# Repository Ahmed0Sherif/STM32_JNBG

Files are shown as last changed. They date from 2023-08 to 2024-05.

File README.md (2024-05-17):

# Intro
- This repository includes the schematics and PCB design of a double-layer STM32 development Board.
- The code name "JNBG" is in the honour of my group who helped and encouraged me in this project.
- The design is done on KiCAD 6.0
# Components List:
|Component|Description|Quantity| Was Used|
|----|-----|---|---|
|STM32f030f4p6|ARM® Cortex®-M0 48MHz FLASH 2.4V ~ 3.6V 32-Bit TSSOP-20 ST Microelectronics|1|Yes|
|AMS1117- 3V3| 3V3 LDO Linear Voltage Regulator  SOT-223-3|1|Yes|
|CH340C|IC Transceiver USB 2.0 2Mbps SOP-16|1|Yes|
|USBLC6-2SC6|ESD Protection TVS Unidirectional Dual Array SOT23-6|1|Yes|
|SMAJ5.0A|Unidirectional TVS 5.0V DO-214AC|1|Not Available|
|Crystal Oscillator|Crystal Oscillator 32MHz 3225|1|Yes|
|LEDs|Green and Red LEDs 0805|1* Green, 1*Red|Yes|
|Ferrite Bead|100Ω @ 100MHz 2.5A 1 100mΩ 0805|1|Yes|
|22uF Capacitor|SMD 22uF 0805|2|Replaced with 1205 Counterpart|
|4.7uF Capacitor|SMD 4.7uF 0603|2|Yes|
|1uF Capacitor|SMD 1uF 0603|2|Yes|
|100n Capacitor|SMD 100nF 0603|1|Yes|
|47nF Capacitor|SMD 47nF 0805|1|Yes|
|10nF Capacitor|SMD 10nF 0603|1|Yes|
|10pF Capacitor|SMD 10pF 0603|2|Yes|
|10k ohm Resistor|SMD 10k 0603|3|Yes|
|1k ohm Resistor|SMD 1k 0603|1|Yes|
|1k5 ohm Resistor|SMD 1k5 0603|3|Yes|
|Tactile Push Button|Micro Push button Switch 2P 3x4x2mm|1|Yes|
|PCB TH SPDT Toggle Switch| Through Hole SPDT Swithc pitch = 2.54mm |1|Yes|
|USB Port|SMD USB-B-Micro |1|Yes|
|Female Headers|TH Female Headers Vertical pitch = 2.54mm|13|Yes|
# Schematics:
## A-Power Module:
<p align="center">

 </p>
<br> - In this circuit, the AMS1117 is used to regulate 5V from USB to 3.3V, with a unidirectional TVS to protect against surges.

## B-USB Interface:
<p align="center">

 </p>
<br> - The board is provided with a USB-B Micro port, providing power and communication to the controller. 
<br> - The differential pair is connected to au nidirectional Dual TVS for ESD protection. Finally, the differentials are connected to a USB-to-TTL interface: CH340C. This variant was chosen because it can operate without an external crystal.
<br> - It is worth mentioning that until this time, this module has not been tested yet.

## C-Main Controller:
<p align="center">

 </p>
### a- Crystal Oscillator
- For calculting the value of capacitors, the following equation is used:
<br>   Capacitor Value =  ( Load Capaitance of Crystal [10pf] + Stray Capacitance of PCB [maximum estimate = 10pF] ) / 2
- Source: Phill's Lab Course on KiCAD 6.0
### b- Power:
- According to the datasheet of STM32f03x, it is recommeded to connect VDD pin to the shown capacitances.
- For more stable ADC performance, a ferrite bead is added to the VDDA connections.
### c- Interfacing:
- GPIO pins are connected to headers for easier interface, while taking speical signals into considerations (i.e. I2C pair)
- A SPDT switch is added to control the BOOT0 pin, and a RST button is added.
- For experimental purposes, extra pair of headers are added to power the STM32 directly, bypassing the regulator.

# PCB View:
<p align="center">
2D View
 </p>
<p align="center">
3D View - Front
 </p>
<p align="center">
3D View - Back
 </p>
 
# Final Result:
<p align="center">
Homemade PCB
 </p>

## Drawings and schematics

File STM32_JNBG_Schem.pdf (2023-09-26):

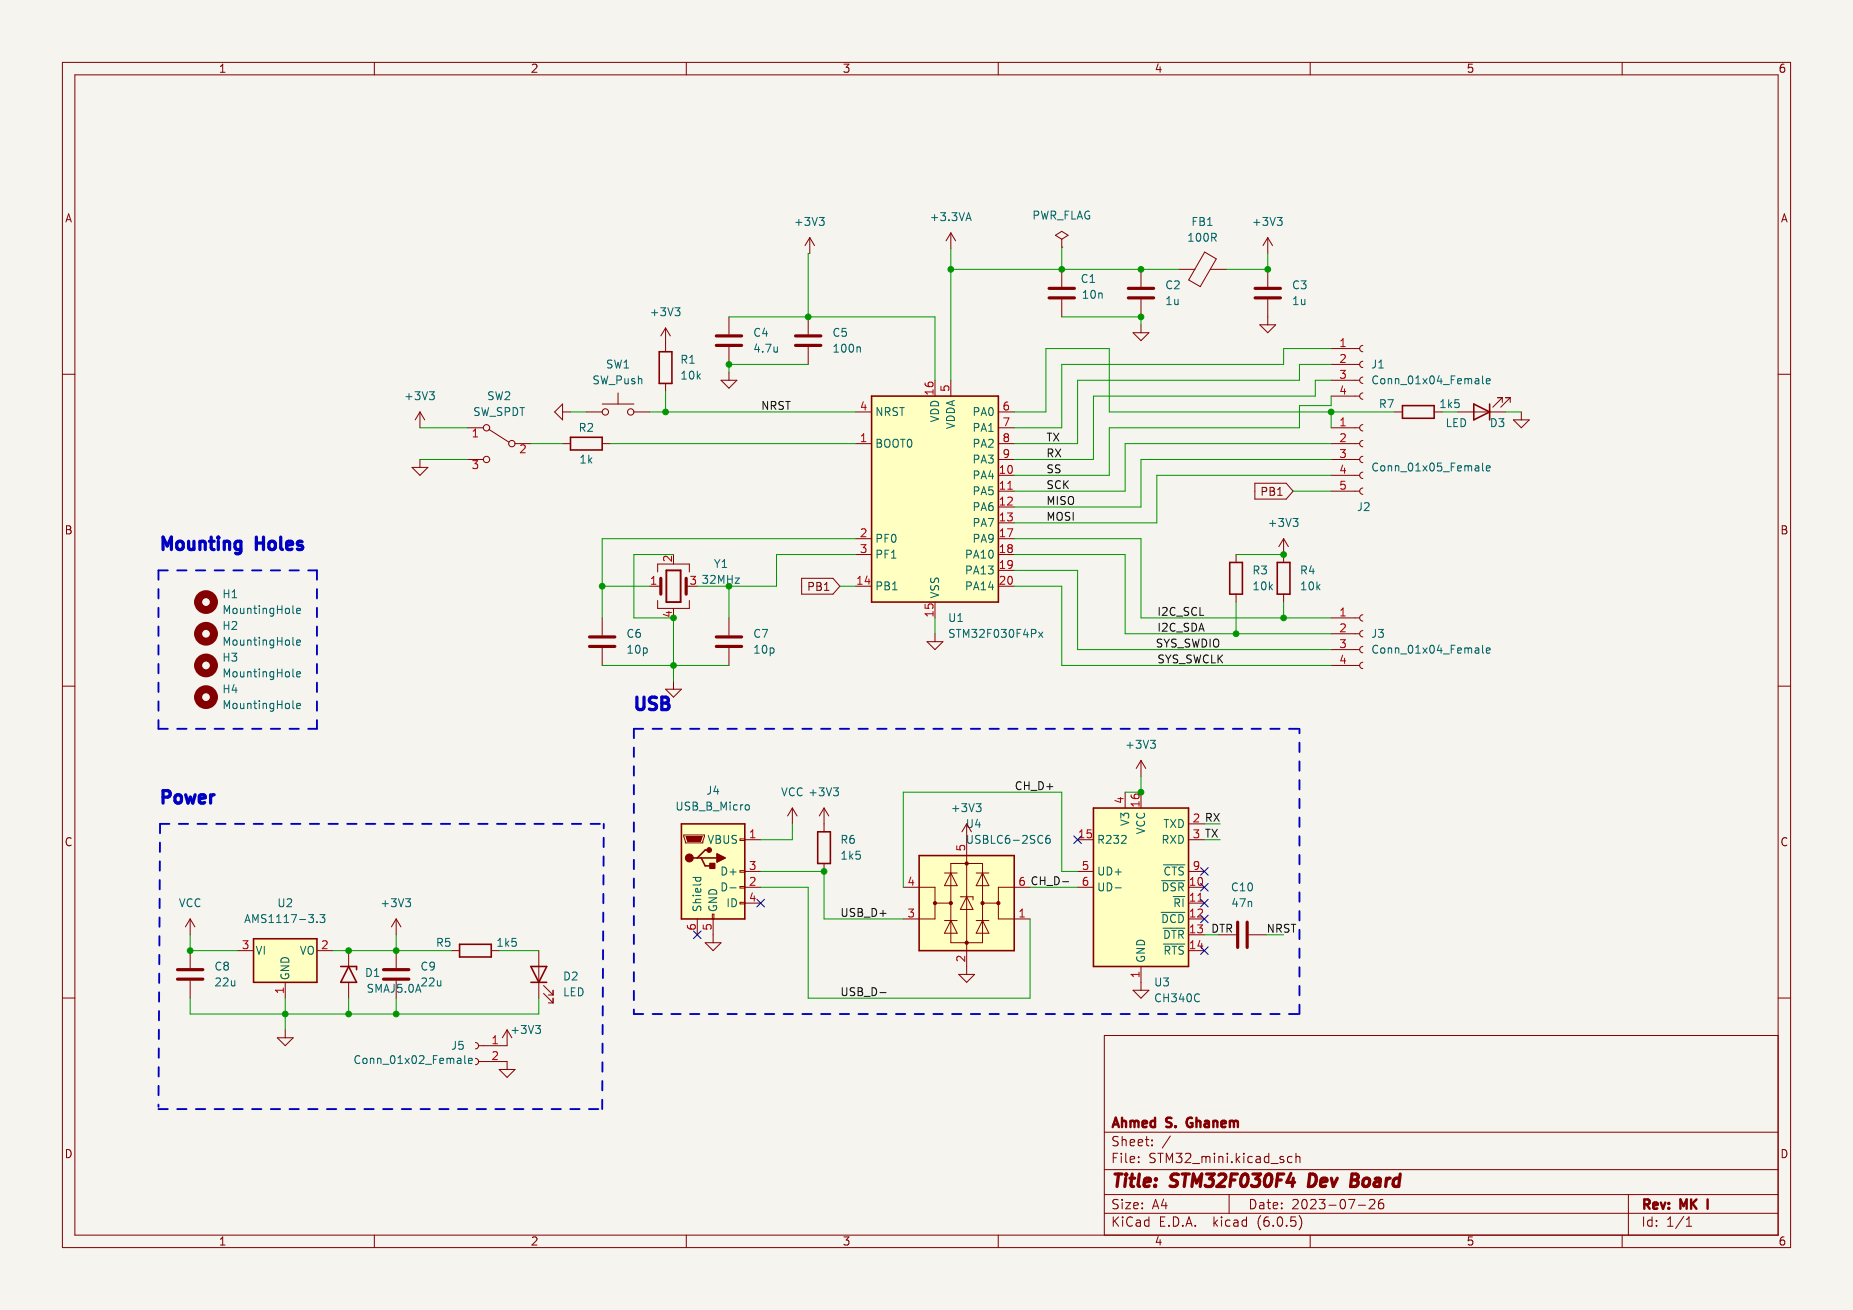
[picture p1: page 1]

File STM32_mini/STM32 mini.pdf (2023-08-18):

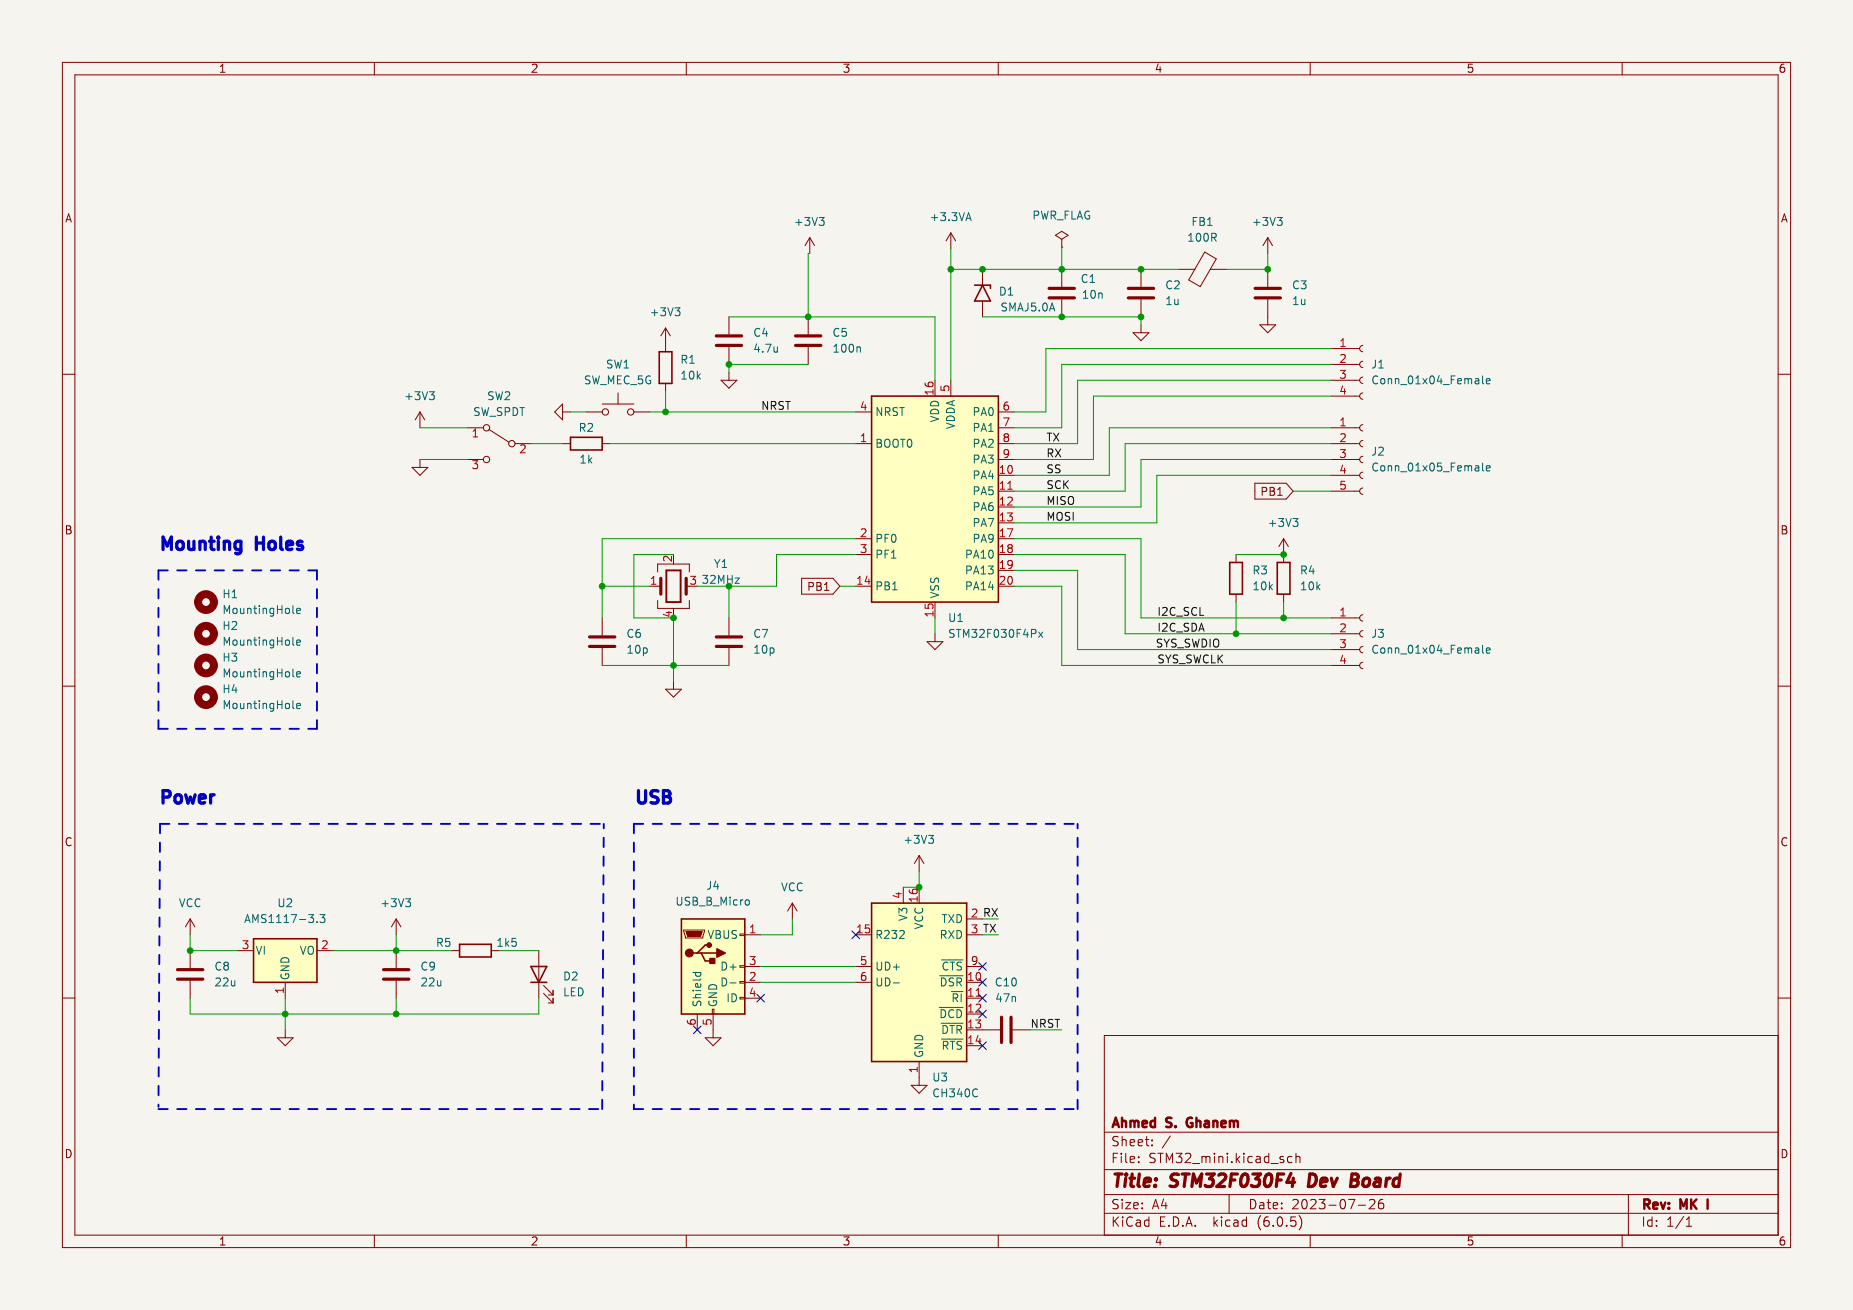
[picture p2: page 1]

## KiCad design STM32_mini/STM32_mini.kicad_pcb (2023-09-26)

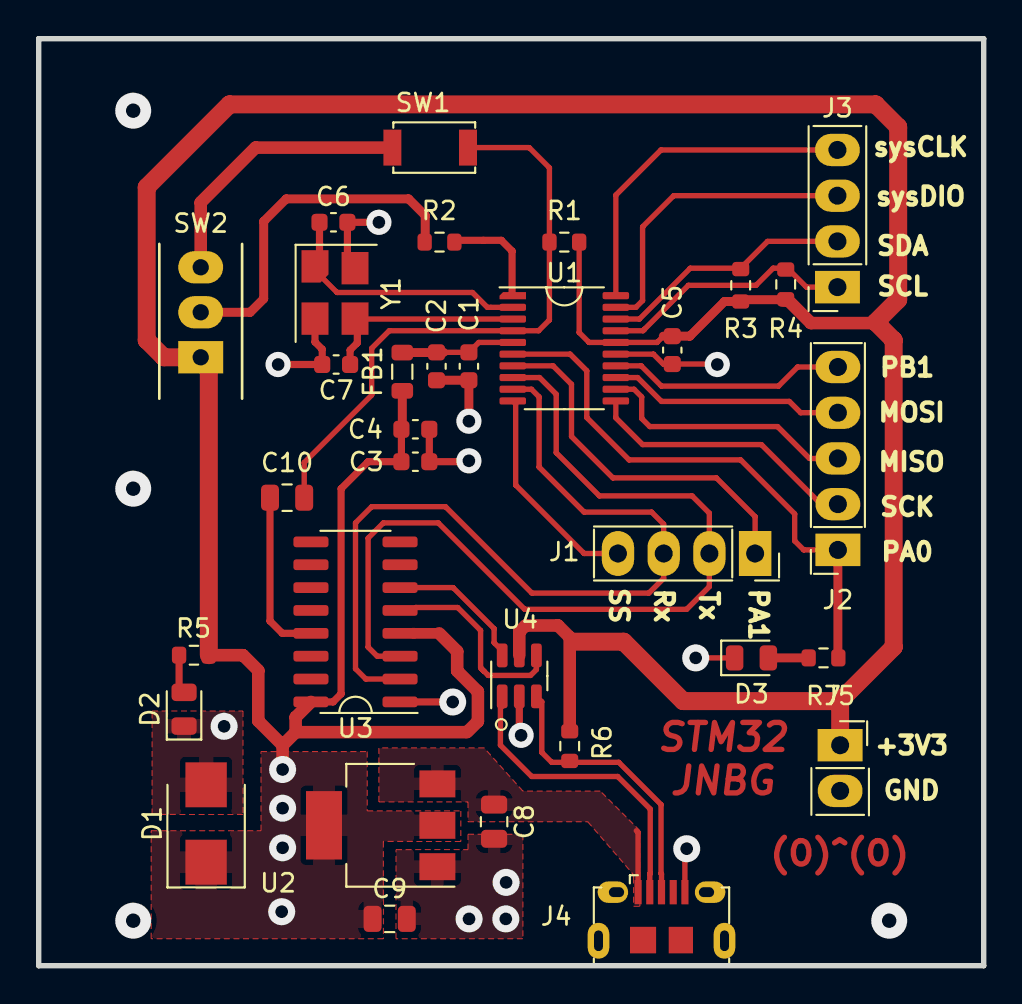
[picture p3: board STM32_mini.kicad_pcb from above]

Board: 2 copper layers, 52.5 x 51.5 mm, 33 parts (0 on the bottom side), 29 nets.

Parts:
C1: 10n; C_0603_1608Metric
C2, C3: 1u; C_0603_1608Metric
C4: 4.7u; C_0603_1608Metric
C5: 100n; C_0603_1608Metric
C6, C7: 10p; C_0603_1608Metric
C8, C9: 22u; C_0805_2012Metric
C10: 47n; C_0805_2012Metric
D1: SMAJ5.0A; D_SMB
D2, D3: LED; LED_0805_2012Metric
FB1: 100R; L_0805_2012Metric
J1, J3: Conn_01x04_Female; PinSocket_1x04_P2.54mm_Vertical
J2: Conn_01x05_Female; PinSocket_1x05_P2.54mm_Vertical
J4: USB_B_Micro; USB_Micro-B_Amphenol_10118194_Horizontal
J5: Conn_01x02_Female; PinSocket_1x02_P2.54mm_Vertical
R1, R3, R4: 10k; R_0603_1608Metric
R2: 1k; R_0603_1608Metric
R5, R6, R7: 1k5; R_0603_1608Metric
SW1: SW_Push; SW_SPST_B3U-1000P
SW2: SW_SPDT; SW_CuK_OS102011MA1QN1_SPDT_Angled
U1: STM32F030F4Px; TSSOP-20_4.4x6.5mm_P0.65mm
U2: AMS1117-3.3; SOT-223-3_TabPin2
U3: CH340C; SOIC-16_3.9x9.9mm_P1.27mm
U4: USBLC6-2SC6; SOT-23-6
Y1: 32MHz; Crystal_SMD_3225-4Pin_3.2x2.5mm_HandSoldering

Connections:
+3.3VA: C1.1, C2.1, FB1.1, U1.5 (VDDA)
+3V3: C3.1, C4.1, C5.1, C9.1, D1.1 (A1), FB1.2, J5.1, R1.1, R3.1, R4.1, R5.1, R6.1, SW2.1 (A), U1.16 (VDD), U2.2 (VO), U3.4 (V3), U3.16 (VCC), U4.5 (VBUS)
/CH_D+: U3.5 (UD+), U4.4 (I/O2)
/CH_D-: U3.6 (UD-), U4.6 (I/O1)
/DTR: C10.2, U3.13 (~DTR)
/I2C_SCL: J3.1, R4.2, U1.17 (PA9)
/I2C_SDA: J3.2, R3.2, U1.18 (PA10)
/MISO: J2.3, U1.12 (PA6)
/MOSI: J2.4, U1.13 (PA7)
/NRST: C10.1, R1.2, SW1.2, U1.4 (NRST)
/RX: J1.3, U1.9 (PA3), U3.2 (TXD)
/SCK: J2.2, U1.11 (PA5)
/SS: J1.4, U1.10 (PA4)
/SYS_SWCLK: J3.4, U1.20 (PA14)
/SYS_SWDIO: J3.3, U1.19 (PA13)
/TX: J1.2, U1.8 (PA2), U3.3 (RXD)
/USB_D+: J4.3 (D+), R6.2, U4.3 (I/O2)
/USB_D-: J4.2 (D-), U4.1 (I/O1)
GND: C1.2, C2.2, C3.2, C4.2, C5.2, C6.2, C7.2, C8.2, C9.2, D1.2 (A2), D2.1 (K), D3.1 (K), J4.5 (GND), J5.2, SW1.1, SW2.3 (C), U1.15 (VSS), U2.1 (GND), U3.1 (GND), U4.2 (GND), Y1.2, Y1.4
unnamed: C6.1, U1.2 (PF0), Y1.1
unnamed: C7.1, U1.3 (PF1), Y1.3
unnamed: D2.2 (A), R5.2
unnamed: D3.2 (A), R7.2
unnamed: J1.1, U1.7 (PA1)
unnamed: J2.1, R7.1, U1.6 (PA0)
unnamed: R2.1, SW2.2 (B)
unnamed: R2.2, U1.1 (BOOT0)
PB1: J2.5, U1.14 (PB1)
VCC: C8.1, J4.1 (VBUS), U2.3 (VI)

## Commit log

2023-08-18 Added files of Project
    [STM32_mini.kicad_pcb, STM32_mini.kicad_sch]
2023-09-26 Update README.md
    Added Some info regarding the development board.
2023-09-26 Overall Design Update
    [STM32_mini.kicad_pcb, STM32_mini.kicad_sch]
2023-09-26 Added Schematics PDF
